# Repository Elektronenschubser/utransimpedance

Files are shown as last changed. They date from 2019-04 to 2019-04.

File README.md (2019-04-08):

# utransimpedance
transimpedance amplifier for measuring low currents with a DMM, inspired by the µcurrent of Dave Jones from the EEVBlog.

All files are licenced under Creative Commons - Share Alike 4.0 International (https://creativecommons.org) 

The PCB is designed to be mounted on an aluminium case from Hammond Manufacturing(R) (1550P or 1550PBK)
Battery holder (Keystone 1120C) should be added.

Estimated technical data:
	Ranges:			6, 10^2 to 10^7 V/A
	Minimal Resolution: 	1pA with 5.5 Digit DMM
	Upper Limit:		10mA
	Maximum Input Current:	160mA(continous), 4A (max. 1µs, non repetive)
	Accuracy:		~0.05%
	Offset			< 2µV
	Bandwidth (-6db):	250kHz
	Power Consumption:	10mW (electronic only)
	Battery Lifetime:	100h-400h (LiFeS2-primary cells, depending on measured current)
	Battery low threshold:	2.64V

directory structure:
	Altium		Altium Circuitstudio(R) source files
	Documentation	pdf documents (schematic, BOM)
	Gerber		mechanical files for production
	STEP		3D CAD model

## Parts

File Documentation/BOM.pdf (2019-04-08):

Description | Designator | Footprint | Quantity Supplier1 Supplier1 Partnumber | Manufacturer | MPN
Connector, BNC THT 50R angled | BNC1, BNC2 | BNC 90° | 2 Völkner V076191 | Telegärtner | J01001A1948
BATTERY HOLDER AAA SMD TAB | BT1, BT2 | Keystone1020 | 2 Digikey 36-1020-ND | Keystone Electronics 1020
Capacitor 100n 20% 0805 | C1, C2, C3, C4, C5, C6 C0805 | 6 Any | Any
CAP CER 10nF 50V C0G/NP0 0805 | C7, C10, C12, C13, C14 C0805 | 5 Digikey 399-7992-1-ND | Kemet | C0805C103J5GACTU
CAP CER 100PF 100V C0G/NP0 0805 C8 | C0805 | 1 Digikey 1276-2569-1-ND | Samsung | CL21C101JC61PNC
CAP CER 1PF 50V NPO 0805 | C9 | C0805 | 1 Digikey 311-4124-1-ND | Yageo | CC0805BRNPO9BN1R0
CAP CER 47PF 50V C0G/NPO 0805 | C11 | C0805 | 1 Digikey 311-1107-1-ND | Yageo | CC0805JRNPO9BN470
DIODE ARRAY GP 70V 215MA SOT23-3 D1 | SOT23-3 | 1 Digikey BAV199LT1GOSCT-ND | ON Semiconductor BAV199LT1G
DIODE SCHOTTKY 30V 140MA SOT23 D2 | SOT23-3 | 1 Digikey TBAT54SLMCT-ND | Toshiba | TBAT54S,LM
TVS DIODE 3.3V 6.8V SOD123FL | D3 | SOD 123-FL | 1 Digikey F7701CT-ND | Littelfuse Inc. | SMF3.3
IC OPAMP GP 10MHZ RRO 8SOIC | IC1 | SO8_N | 1 Digikey AD8692ARZ-REELCT-ND Analog Devices | AD8692ARZ
OpAmp, low noise, auto zero | IC2, IC3 | SOT23-6 | 2 Digikey MAX4238AUT+TCT-ND Maxim Integrated | MAX4238AUT+T
IC VOLT SUPERVISOR 2.64V SOT23-3 IC4 | SOT23-3 | 1 Digikey 296-29195-1-ND | Texas Instruments | TLV803RDBZR
LED rot 1206 revers | LED1 | LED_1206_revers | 1 Digikey 732-5031-1-ND | Würth Elektronik | 156120RS75300
MOSFET P-CH 30V 470MA SOT23 | Q1 | SOT23-3 | 1 Digikey 1727-6216-1-ND | Nexperia | BSH203,215
MOSFET N-CH 20V 1.7A SOT23-3 | Q2 | SOT23-3 | 1 Digikey ZXM61N02FCT-ND | Diodes Inc. | ZXM61N02FTA
Resistor 270R 1% 0805 | R1 | R0805 | 1 Any | Any
RES SMD 47 OHM 0.05% 1/8W 0805 | R2 | R0805 | 1 Digikey RG20N47WCT-ND | Susumu | RG2012N-470-W-T1
RES SMD 4k7 OHM 0.05% 1/8W 0805 | R3, R6 | R0805 | 2 Digikey P4.7KBSCT-ND | Panasonic | ERA-6ARW472V
RES SMD 470K OHM 0.05% 1/8W 0805 R4 | R0805 | 1 Digikey RG20N470KWCT-ND | Susumu | RG2012N-474-W-T1
RES SMD 470 OHM 0.05% 1/8W 0805 R5 | R0805 | 1 Digikey RG20N470WCT-ND | Susumu | RG2012N-471-W-T1
Resistor 1M 1% 0805 | R7, R10 | R0805 | 2 Any | Any
Resistor 100k 1% 0805 | R8, R12 | R0805 | 2 Any | Any
RES SMD 10K OHM 0.05% 1/8W 0805 R9 | R0805 | 1 Digikey RG20N10.0KWCT-ND | Susumu | RG2012N-103-W-T1
Resistor 49R9 1% 0805 | R11 | R0805 | 1 Any | Any
Switch, DPDT THT mini | SW1 | MMP 221 | 1 Völkner D73482 | Knitterswitch | 221
DP6T Rotary Switch | SW2 | MKF206 | 1 Digikey 360-2371-ND | NKK Switches | MRF206

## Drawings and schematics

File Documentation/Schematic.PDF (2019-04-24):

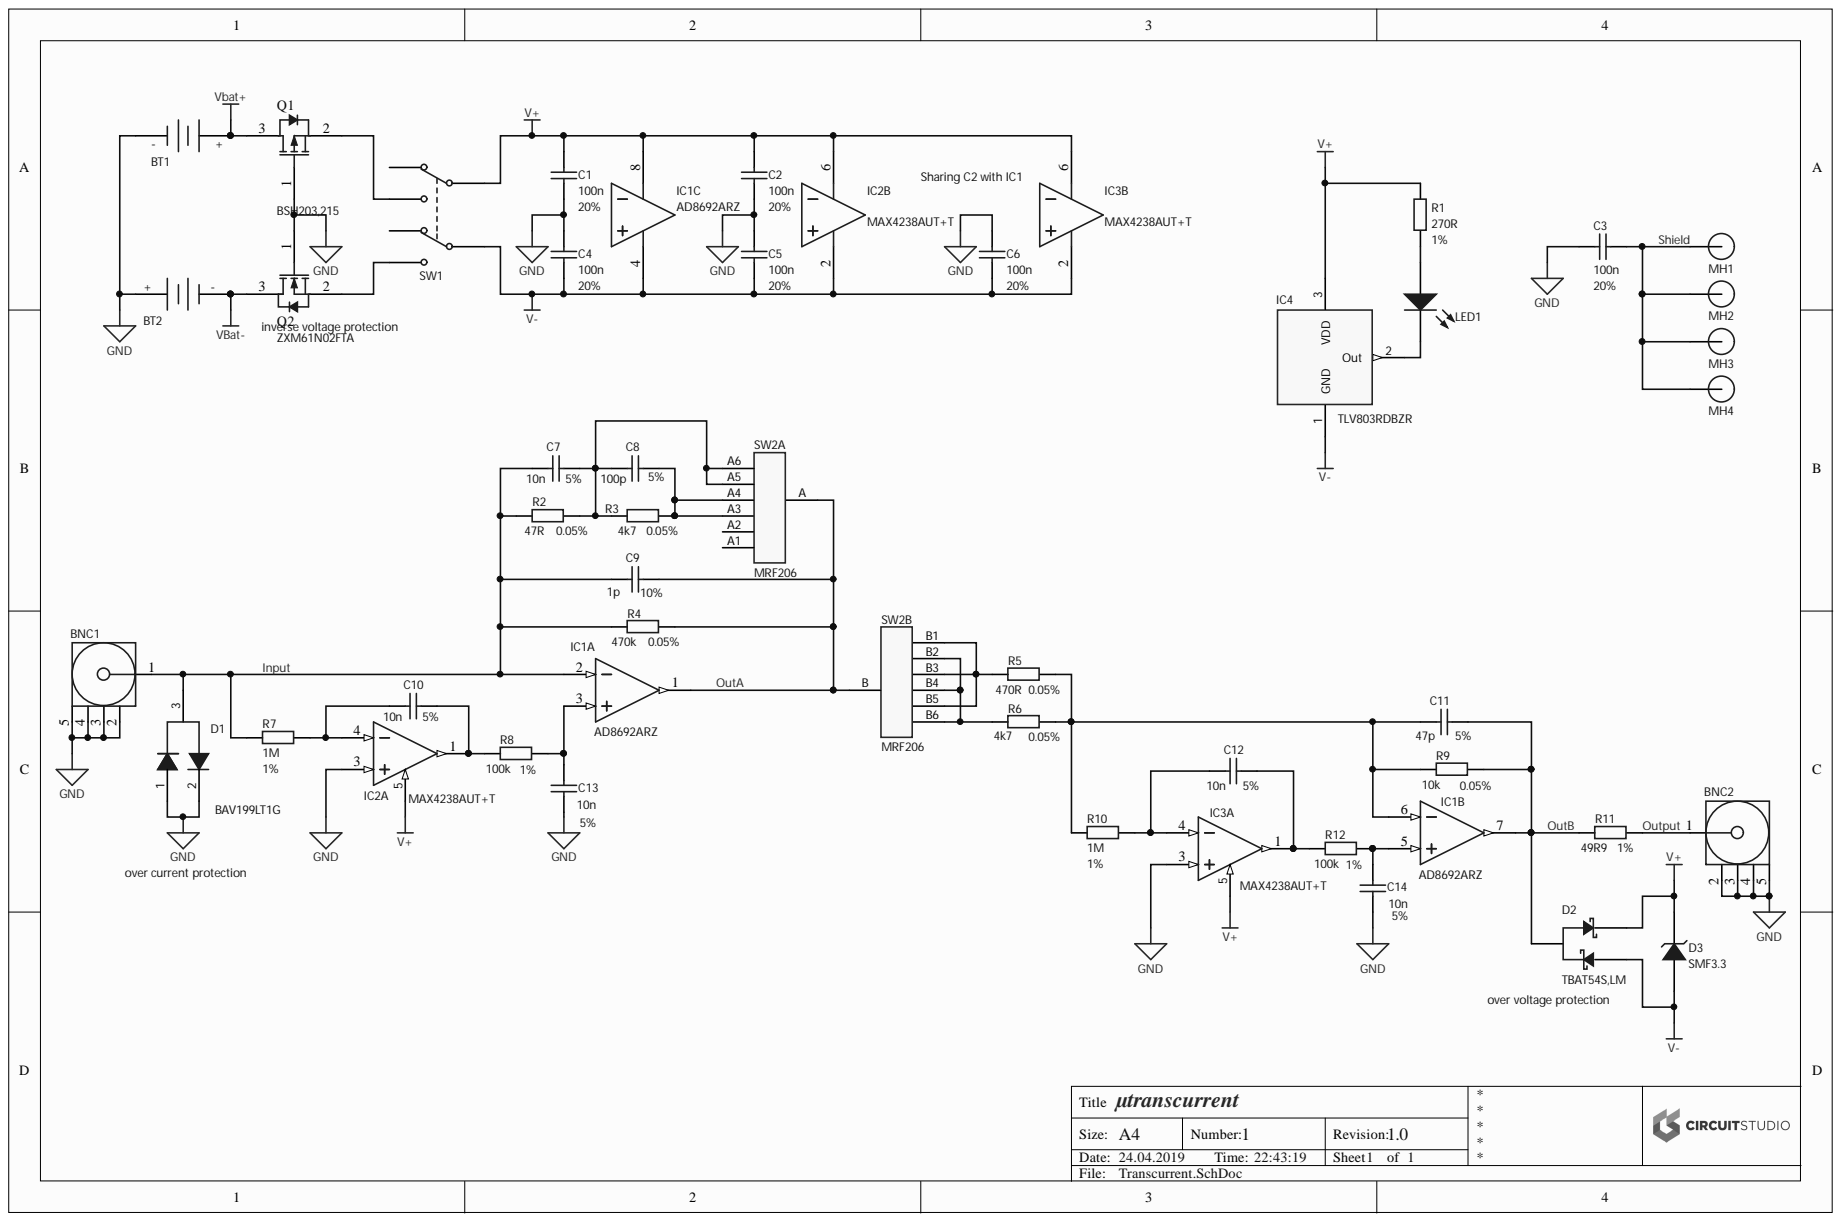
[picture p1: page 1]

A4
A3

B2
B3
B4
B5

µtranscurrent Title | * * * * *

A4 Size: | 1 Number: | 1.0 Revision:
Date: 24.04.2019 Time: 22:43:19 | | Sheet 1 of 1

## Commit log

2019-04-08 First Prototype
    [BOM.xls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]
2019-04-24 COrrections after testing of the prototype: Pin assignment of Q1 and Q2 corrected. The copper toplayer was changed.
    [BOM.xls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]
